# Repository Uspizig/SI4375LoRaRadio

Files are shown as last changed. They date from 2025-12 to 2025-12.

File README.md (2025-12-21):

# SensePuck_Radio: The Triple Tuner Platform for Meshtastic, LoRa, FM & AM

<p align="center"> 
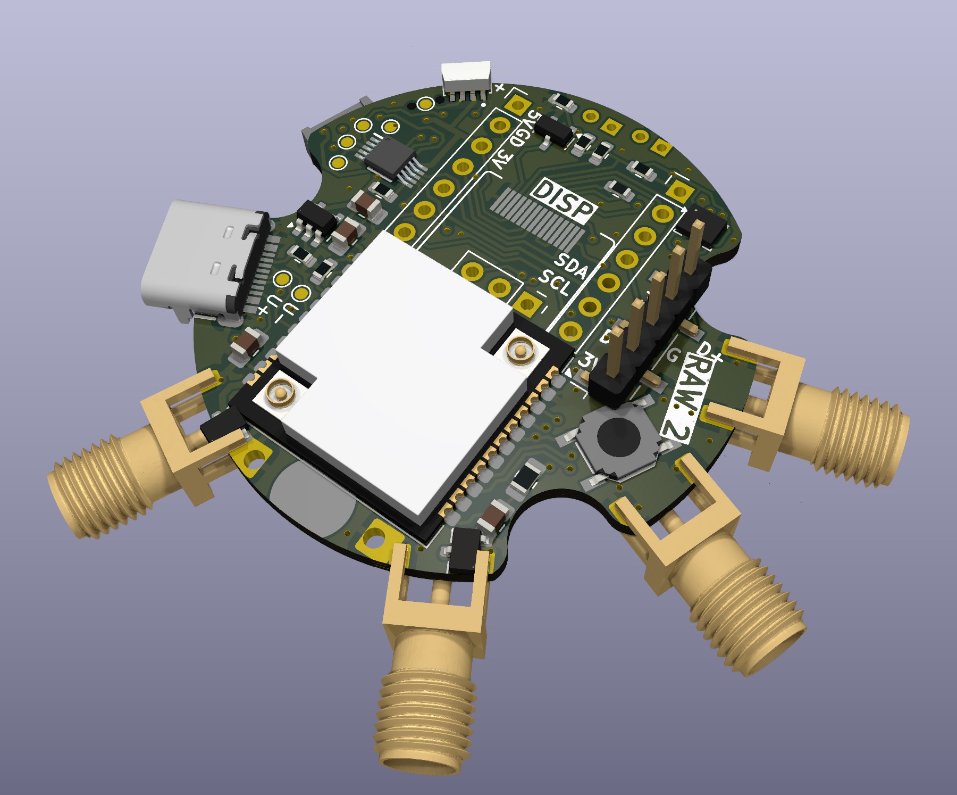
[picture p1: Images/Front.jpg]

</p>

<p align="center"> 
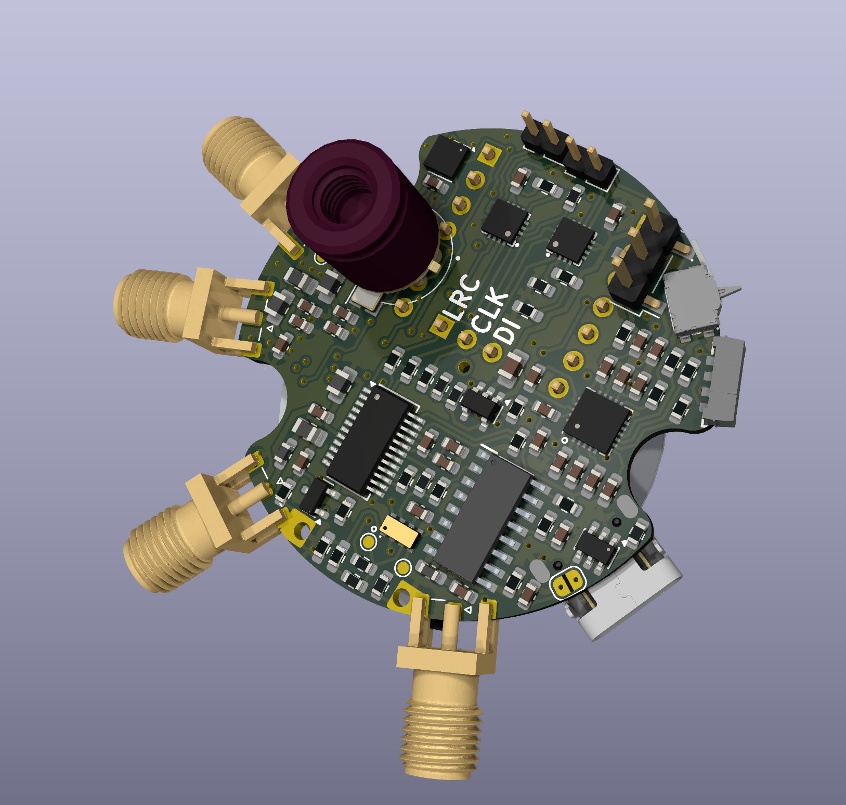
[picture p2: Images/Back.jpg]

</p>

 <p align="center"> 
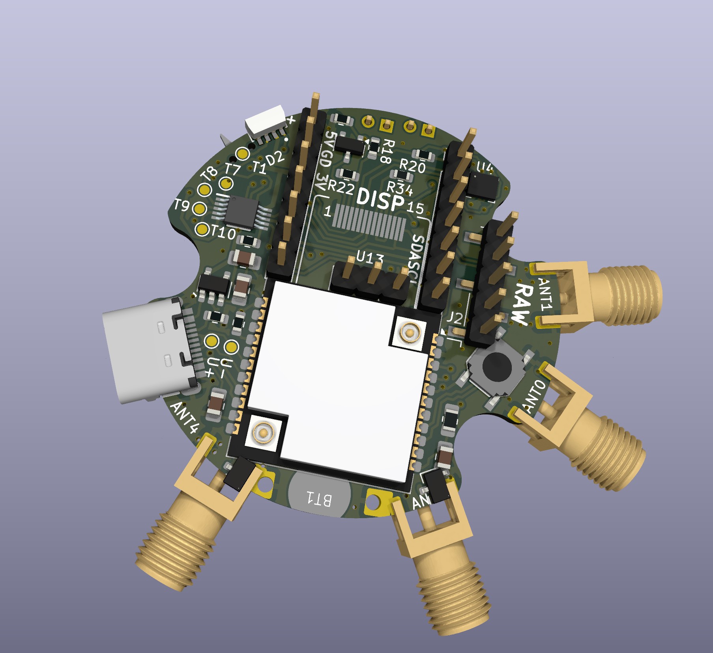
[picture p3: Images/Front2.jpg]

</p>

## Features:

1. **2xAudioAmplifier MAX98357**: Listen to your favourite Tunes with an Audio Amplifier

2. **SI4735 with Digital and Analog Audio**: Listen to AM/FM Radio

3. **SI4732 with Analog Audio**: Listen to AM/FM Radio

4.  **Heltec Lora HT-CT62 **: For Recieving and Transmitting LoRa, Meshtastic, TheThingsNetwork, Meshcore or decode your Bresser Weather Station

5.  SI5351 VCO Generator, 3 RF Outputs: 2.5 kHz to 160MHz 

6. **I2C Connector for Sensor**: Connect your favourite I2C Sensor board with the embedded 2.54mm connector

7. **Wireless Control**: Untehther your development process with the wireless capabilities. With WiFi and BLE, this tool allows remote control and data logging. Users can adjust settings and monitor data from a distance, offering a more flexible development experience.

8. **USB-C Connector**: for Debuggung and Power Supply

9. **LSM6 Gyro+ACC**: Check Movements, Steps Pedometer

10. TC4057 Battery Charger (Optional)

11. VEML 7700 Light Sensor (Optional)

12. GPS Sensor (Optional)

13. MLX90640/MLX90614 Thermal Sensor (Optional)

14. **Open Source & Programmable**: As an open-source device, the Device offers unmatched versatility. It is fully programmable, allowing you to tailor its functionality to your specific applications. This customization extends to software and hardware, opening up endless possibilities for creative and efficient project development.

15. **Compact Design**: Designed for convenience, the LoRaCam Board compact and sleek form factor allows for seamless integration into existing setups. Its compatibility with USB PD power sources and inline integration capability minimizes the need for additional equipment or extensive redesign, making it a versatile and user-friendly addition to any development environment.

16. **Display+Touchscreeen**: Monitor live the current status on an 1.8" or 1.28" LCD Touch Display

17. **RTC**: RealTimeClock RV3032 Temp Compensated for RealTime Clock

18. Extension Modules - Compatible to Seeed Sensors and Displays
<p align="center"> 
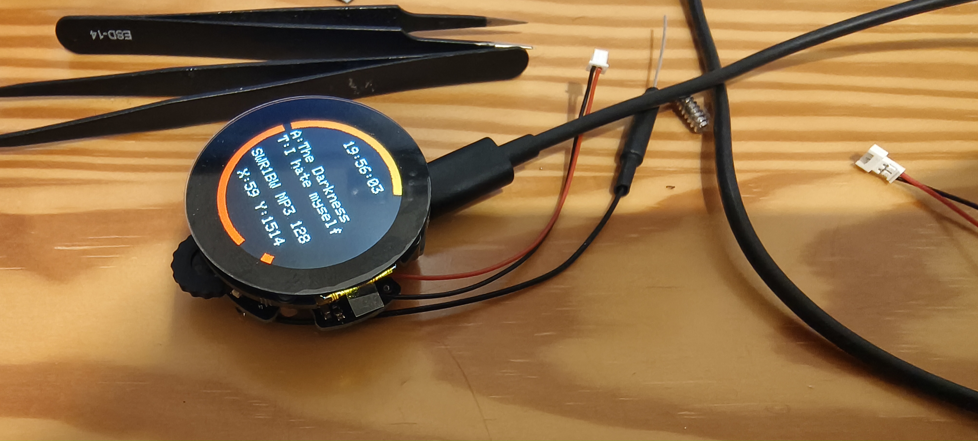
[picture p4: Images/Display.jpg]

</p>

19. **RGB LED**: Status LED WS2812-4020

20.  BME680: Measure Temperature, Humidity, Air Pressure, TVOC, eCO² (might update to BME688 or BME690 soon)
    
## Specifications

<p align="center"> 
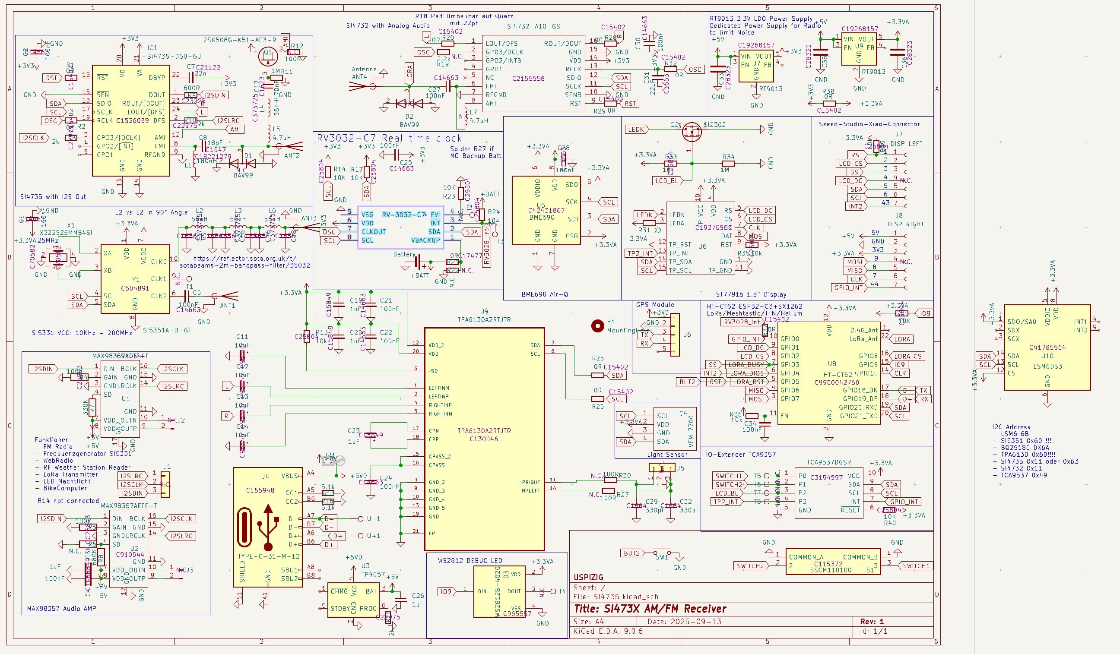
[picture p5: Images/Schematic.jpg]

</p>

<p align="center"> 
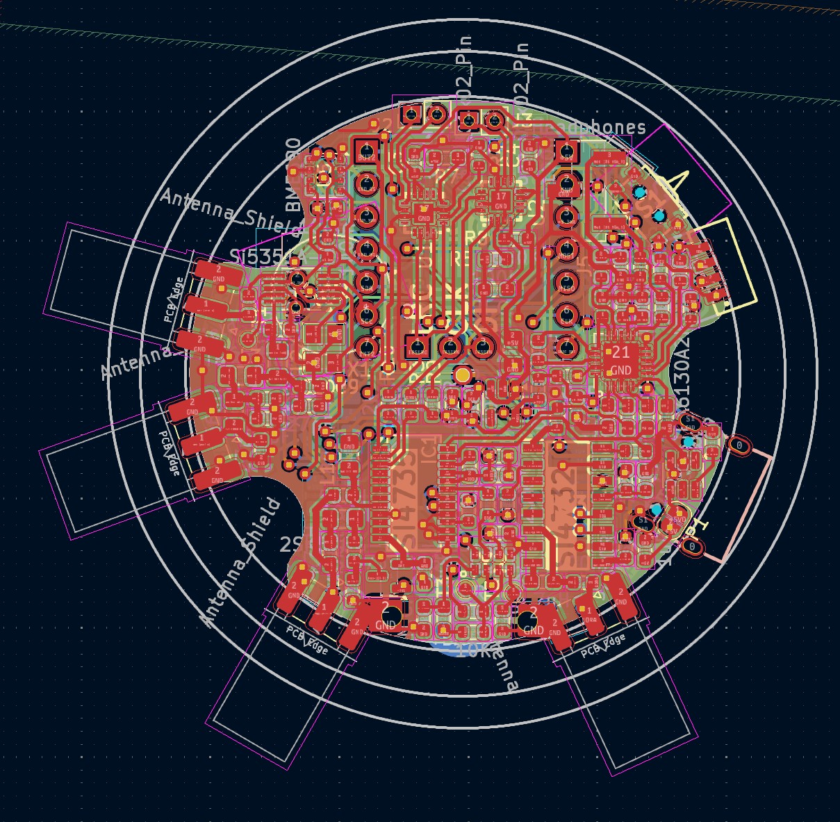
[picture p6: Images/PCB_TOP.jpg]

</p>

<p align="center"> 
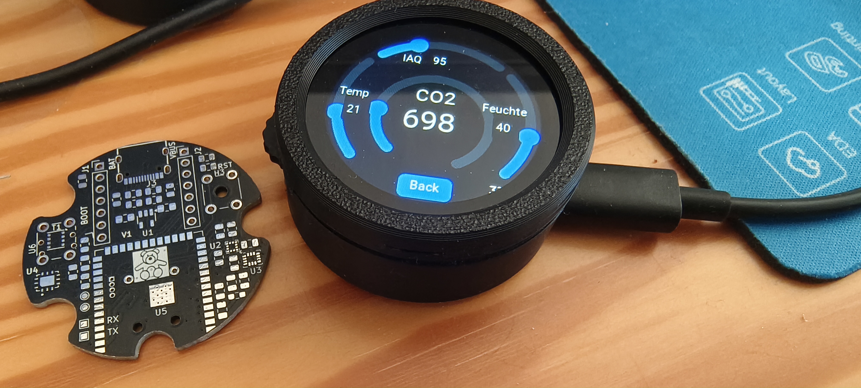
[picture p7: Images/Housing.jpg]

</p>

<p align="center"> 
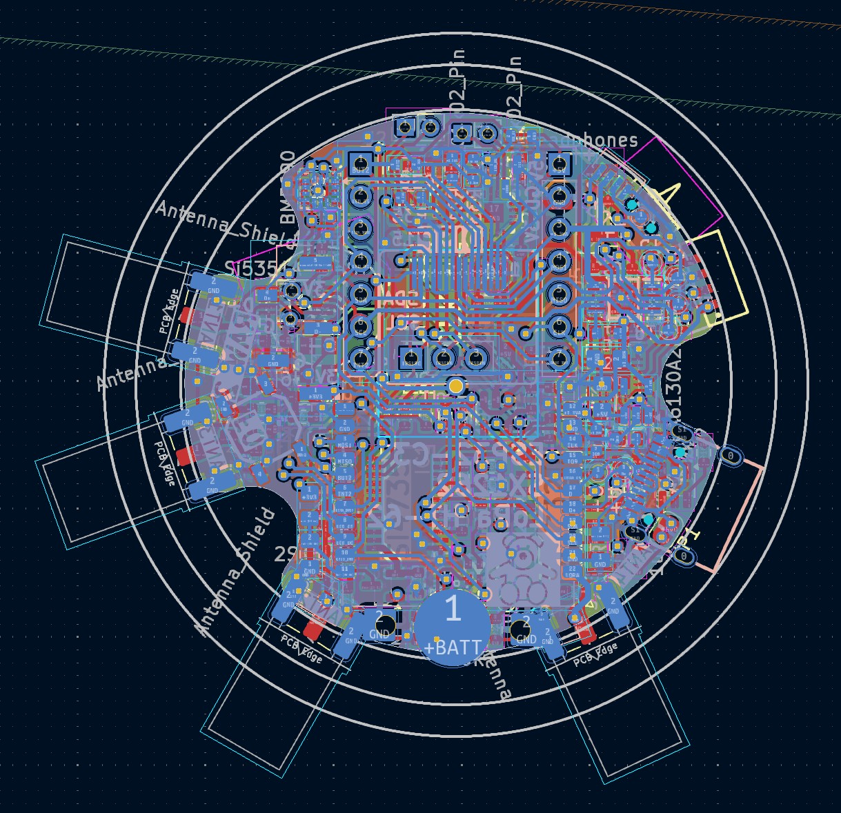
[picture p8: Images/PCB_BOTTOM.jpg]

</p>

Needed Libaries:

https://github.com/schreibfaul1/ESP32-audioI2S
https://github.com/pololu/lis3mdl-arduino
https://github.com/pololu/lsm6-arduino
https://github.com/Seeed-Projects/SeeedStudio_TFT_eSPI
https://github.com/Seeed-Projects/SeeedStudio_lvgl
https://github.com/Seeed-Studio/Seeed_Arduino_RoundDisplay

### Key Features:

### Future Developments:

AI Detection of objects, radio Signal and determine if the device shall sent the data via LoRa 

## Testing for Performance

At the heart of SensePuck's design is a commitment to reliability and performance. To ensure that SensePuck stands up to real-world demands, we subjected it to testing under use conditions.

## License

MIT License

Copyright (c) 2025 blue2monster

Permission is hereby granted, free of charge, to any person obtaining a copy
of this software and associated documentation files (the "Software"), to deal
in the Software without restriction, including without limitation the rights
to use, copy, modify, merge, publish, distribute, sublicense, and/or sell
copies of the Software, and to permit persons to whom the Software is
furnished to do so, subject to the following conditions:

The above copyright notice and this permission notice shall be included in all
copies or substantial portions of the Software.

THE SOFTWARE IS PROVIDED "AS IS", WITHOUT WARRANTY OF ANY KIND, EXPRESS OR
IMPLIED, INCLUDING BUT NOT LIMITED TO THE WARRANTIES OF MERCHANTABILITY,
FITNESS FOR A PARTICULAR PURPOSE AND NONINFRINGEMENT. IN NO EVENT SHALL THE
AUTHORS OR COPYRIGHT HOLDERS BE LIABLE FOR ANY CLAIM, DAMAGES OR OTHER
LIABILITY, WHETHER IN AN ACTION OF CONTRACT, TORT OR OTHERWISE, ARISING FROM,
OUT OF OR IN CONNECTION WITH THE SOFTWARE OR THE USE OR OTHER DEALINGS IN THE
SOFTWARE.

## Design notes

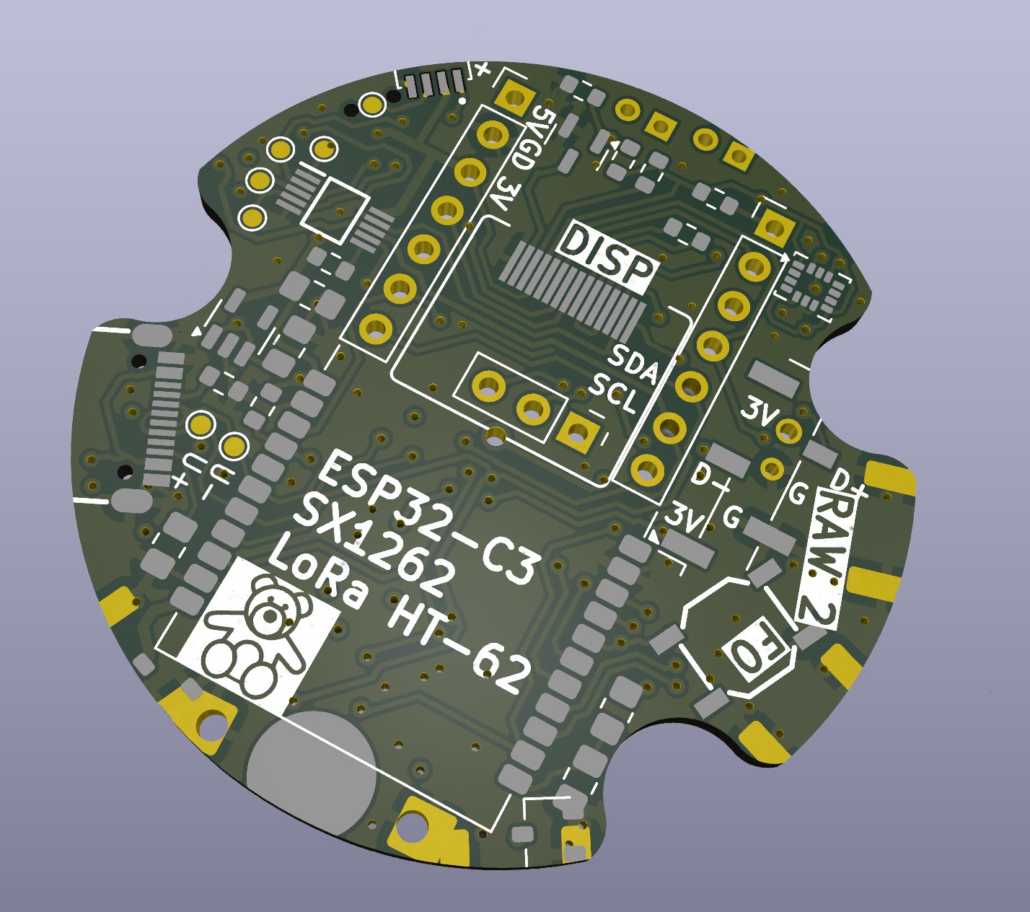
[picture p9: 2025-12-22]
Images/FrontRAW.jpg

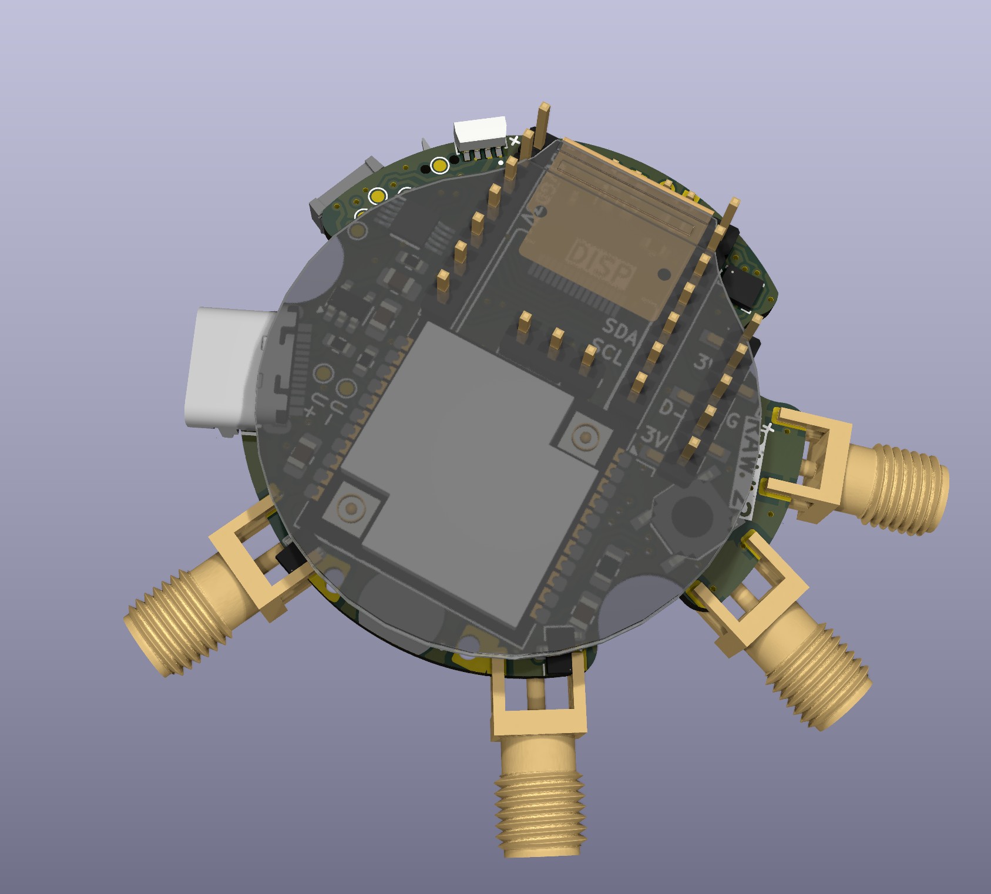
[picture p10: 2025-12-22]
Images/Front_Display.jpg

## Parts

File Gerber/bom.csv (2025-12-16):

Designator | Footprint | Quantity | Value | LCSC Part #
ANT0, ANT1, ANT5 | SMA_Samtec_SMA-J-P-H-ST-EM1_EdgeMount | 3 | Antenna_Shield
ANT4 | SMA_Samtec_SMA-J-P-H-ST-EM1_EdgeMount | 1 | Antenna
BT1 | MYOUNG MY-927-01 | 1 | Battery
C10, C11, C8, C9 | 0603 | 4 | 10uF
C14, C15, C16, C20 | 0603 | 4 | 1uF
C17, C18, C19, C21, C22, C23, C24, C27, C33, C37, C44, C49 | 0603 | 12 | 100nF
C28, C29, C30 | 0805 | 3 | 1uF
C32 | 0603 | 1 | 22n
C34, C39 | 0603 | 2 | 270p
C36 | 0603 | 1 | 18pF
C38, C40, C41, C43, C46, C47 | 0603 | 6 | 27pF
C42 | 0603 | 1 | 22pF
C45 | 0805 | 1 | 100nF
C48 | 0603 | 1 | 470nF
D2 | LED_WS2812B-4020 | 1 | WS2812B-4020
D6, D7 | SOT-23W | 2 | BAV99
IC1 | SOIC127P600X175-16N | 1 | SI4732-A10-GS
IC2 | SOP50P490X110-10N | 1 | TCA9537DGSR
J1 | PinHeader_1x03_P2.54mm_Vertical | 1 | Conn_01x03
J2 | PinHeader_1x05_P2.54mm_Vertical_SMD_Pin1Right | 1 | Conn_01x05
J3 | PinHeader_1x03_P2.54mm_Vertical_SMD_Pin1Left | 1 | Headphones
J5 | PinHeader_1x07_P2.54mm_Vertical | 1 | DISP LEFT
J6 | PinHeader_1x07_P2.54mm_Vertical | 1 | DISP RIGHT
J7, J9 | PinHeader_1x02_P2.00mm_Vertical | 2 | Conn_01x02_Pin
J8 | USB-C_SMD-TYPE-C-31-M-12 | 1 | TYPE-C-31-M-12
L1, L2, L3, L6 | 0805 | 4 | 56nH
L4 | 0805 | 1 | 180nH
L5 | 0805 | 1 | 4.7uH
L7 | 0603 | 1 | 4.7uH
Q2 | SOT-23 | 1 | 2N7002
Q3 | SOT-23 | 1 | 2SK508G-K51-AE3-R
R1, R18, R20, R34, R47, R52 | 0603 | 6 | 10k
R10, R11, R48 | 0603 | 3 | 100R
R12, R13, R24, R25 | 0603 | 4 | 10K | C17414
R14 | 0603 | 1 | N.C.
R15 | 0603 | 1 | 0R | C17414
R16, R7 | 0603 | 2 | 100K
R17 | 0603 | 1 | 680K
R19, R50 | 0603 | 2 | 1M
R2, R23, R26, R28, R39, R45, R53, R8, R9 | 0603 | 9 | 0R
R21 | 0603 | 1 | 330K
R22 | 0603 | 1 | 22
R27 | 0603 | 1 | N.C. | C17414
R38, R40, R41 | 0603 | 3 | 2k
R42 | 0603 | 1 | 600R
R44 | 0805 | 1 | 10k
R46 | 0805 | 1 | 0R
R49 | 0603 | 1 | 5.1k
R51 | 0805 | 1 | 5.1k
S1 | SSCM110100 | 1 | SSCM110100
SW1 | SW-SMD_4P-CORR-L5.2-W5.2-P3.70-LS6.4 | 1 | SW_Push
T1, T10, T11, T5, T6, T7, T8, T9 | TestPoint_Pad_D1.0mm | 8 | TestPoint
U+1 | TestPoint_Pad_D1.0mm | 1 | U+
U-1 | TestPoint_Pad_D1.0mm | 1 | U-
U1 | Heltec_HT-CT62 | 1 | HT-CT62
U11, U6 | SOT-23-5 | 2 | RT9013
U13 | GC9A01_Touch_IPS_display_reversed_16pin | 1 | ~
U2 | Bosch_LGA-8_3x3mm_P0.8mm_ClockwisePinNumbering | 1 | BME690
U4 | LGA-14_3x2.5mm_P0.5mm_LayoutBorder3x4y | 1 | LSM6DS3
U5 | QFN-20-1EP_4x4mm_P0.5mm_EP2.7x2.7mm | 1 | TPA6130A2RTJTR | TPA6130A2RTJTR
U7, U8 | TQFN-16_L3.0-W3.0-P0.50-BL-EP1.5 | 2 | MAX98357AETE+T
U9 | SSOP-24_3.9x8.7mm_P0.635mm | 1 | Si4735-D60-GU
X1 | Crystal_SMD_3225-4Pin_3.2x2.5mm | 1 | X322525MMB4SI
Y1 | MSOP-10_3x3mm_P0.5mm | 1 | Si5351A-B-GT
Y2 | RV3032C7 | 1 | RV-3032-C7

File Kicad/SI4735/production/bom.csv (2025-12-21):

Designator | Footprint | Quantity | Value | LCSC Part #
ANT1, ANT2, ANT3 | SMA_Samtec_SMA-J-P-H-ST-EM1_EdgeMount | 3 | Antenna_Shield
ANT4 | SMA_Samtec_SMA-J-P-H-ST-EM1_EdgeMount | 1 | Antenna
BT1 | MYOUNG MY-927-01 | 1 | Battery
C1, C2, C22, C23, C25, C26, C27, C28, C31, C4, C6 | 0603 | 11 | 100nF
C10, C20, C21, C24, C3 | 0603 | 5 | 1uF
C11, C16, C17, C19, C5, C9 | 0603 | 6 | 27pF
C12, C13, C14, C15 | 0603 | 4 | 10uF
C18 | 0603 | 1 | 470nF
C30, C33 | 0603 | 2 | 330pF
C32 | 0603 | 1 | 22pF
C34, C36, C37 | 0805 | 3 | 1uF
C35 | 0805 | 1 | 100nF
C7 | 0603 | 1 | 22n
C8 | 0603 | 1 | 18pF
D1, D2 | SOT-23W | 2 | BAV99
D3 | LED_WS2812B-4020 | 1 | WS2812B-4020
IC1 | SOIC127P600X175-16N | 1 | SI4732-A10-GS
IC2 | VEML7700 | 1 | VEML7700
IC3 | SOP50P490X110-10N | 1 | TCA9537DGSR
IC4 | MLX90640ESFBAB000SP | 1 | MLX90640ESF-BAB-000-SP
J1 | PinHeader_1x03_P2.54mm_Vertical | 1 | Conn_01x03
J2, J3 | PinHeader_1x02_P2.00mm_Vertical | 2 | Conn_01x02_Pin
J4 | USB-C_SMD-TYPE-C-31-M-12 | 1 | TYPE-C-31-M-12
J5 | PinHeader_1x03_P2.54mm_Vertical_SMD_Pin1Left | 1 | Headphones
J6 | PinHeader_1x05_P2.54mm_Vertical_SMD_Pin1Right | 1 | Conn_01x05
J7 | PinHeader_1x07_P2.54mm_Vertical | 1 | DISP LEFT
J8 | PinHeader_1x07_P2.54mm_Vertical | 1 | DISP RIGHT
JP1 | SolderJumper-2_P1.3mm_Open_RoundedPad1.0x1.5mm | 1 | Jumper_2_Small_Open
L1 | 0805 | 1 | 180nH
L2, L3, L4, L6 | 0805 | 4 | 56nH
L5, L7 | 0603 | 2 | 4.7uH
Q1 | SOT-23 | 1 | 2SK508G-K51-AE3-R
Q2 | SOT-23 | 1 | SI2302
R1, R18, R19, R2, R24, R25, R28, R29, R31, R36, R37 | 0603 | 11 | 0R
R10, R3, R41 | 0603 | 3 | 2k
R11, R33 | 0603 | 2 | 1M
R12, R26, R27 | 0603 | 3 | 100R
R13, R32, R34, R38, R39, R40 | 0603 | 6 | 10k
R14, R17, R22, R23 | 0603 | 4 | 10K | C17414
R15 | 0603 | 1 | 5.1k
R16 | 0805 | 1 | 5.1k
R20 | 0603 | 1 | 0R | C17477
R21 | 0603 | 1 | N.C. | C17414
R30 | 0603 | 1 | 22
R35 | 0805 | 1 | 10k
R4, R5 | 0603 | 2 | 100K
R6 | 0603 | 1 | N.C.
R7 | 0603 | 1 | 330K
R8 | 0603 | 1 | 680K
R9 | 0603 | 1 | 600R
S1 | SSCM110100 | 1 | SSCM110100
SW1 | SW-SMD_4P-CORR-L5.2-W5.2-P3.70-LS6.4 | 1 | SW_Push
T1, T2, T3, T4, T5, T6, T7, T8 | TestPoint_Pad_D1.0mm | 8 | TestPoint
U+1 | TestPoint_Pad_D1.0mm | 1 | U+
U-1 | TestPoint_Pad_D1.0mm | 1 | U-
U1 | SSOP-24_3.9x8.7mm_P0.635mm | 1 | Si4735-D60-GU
U10 | LGA-14_3x2.5mm_P0.5mm_LayoutBorder3x4y | 1 | LSM6DS3
U12 | TSOT-23-6 | 1 | TP4057
U2, U3 | TQFN-16_L3.0-W3.0-P0.50-BL-EP1.5 | 2 | MAX98357AETE+T
U4 | QFN-20-1EP_4x4mm_P0.5mm_EP2.7x2.7mm | 1 | TPA6130A2RTJTR | TPA6130A2RTJTR
U5 | Bosch_LGA-8_3x3mm_P0.8mm_ClockwisePinNumbering | 1 | BME690
U6 | GC9A01_Touch_IPS_display_reversed_16pin | 1 | ~
U7, U9 | SOT-23-5 | 2 | RT9013
U8 | Heltec_HT-CT62 | 1 | HT-CT62
X1 | Crystal_SMD_3225-4Pin_3.2x2.5mm | 1 | X322525MMB4SI
Y1 | MSOP-10_3x3mm_P0.5mm | 1 | Si5351A-B-GT
Y2 | RV3032C7 | 1 | RV-3032-C7

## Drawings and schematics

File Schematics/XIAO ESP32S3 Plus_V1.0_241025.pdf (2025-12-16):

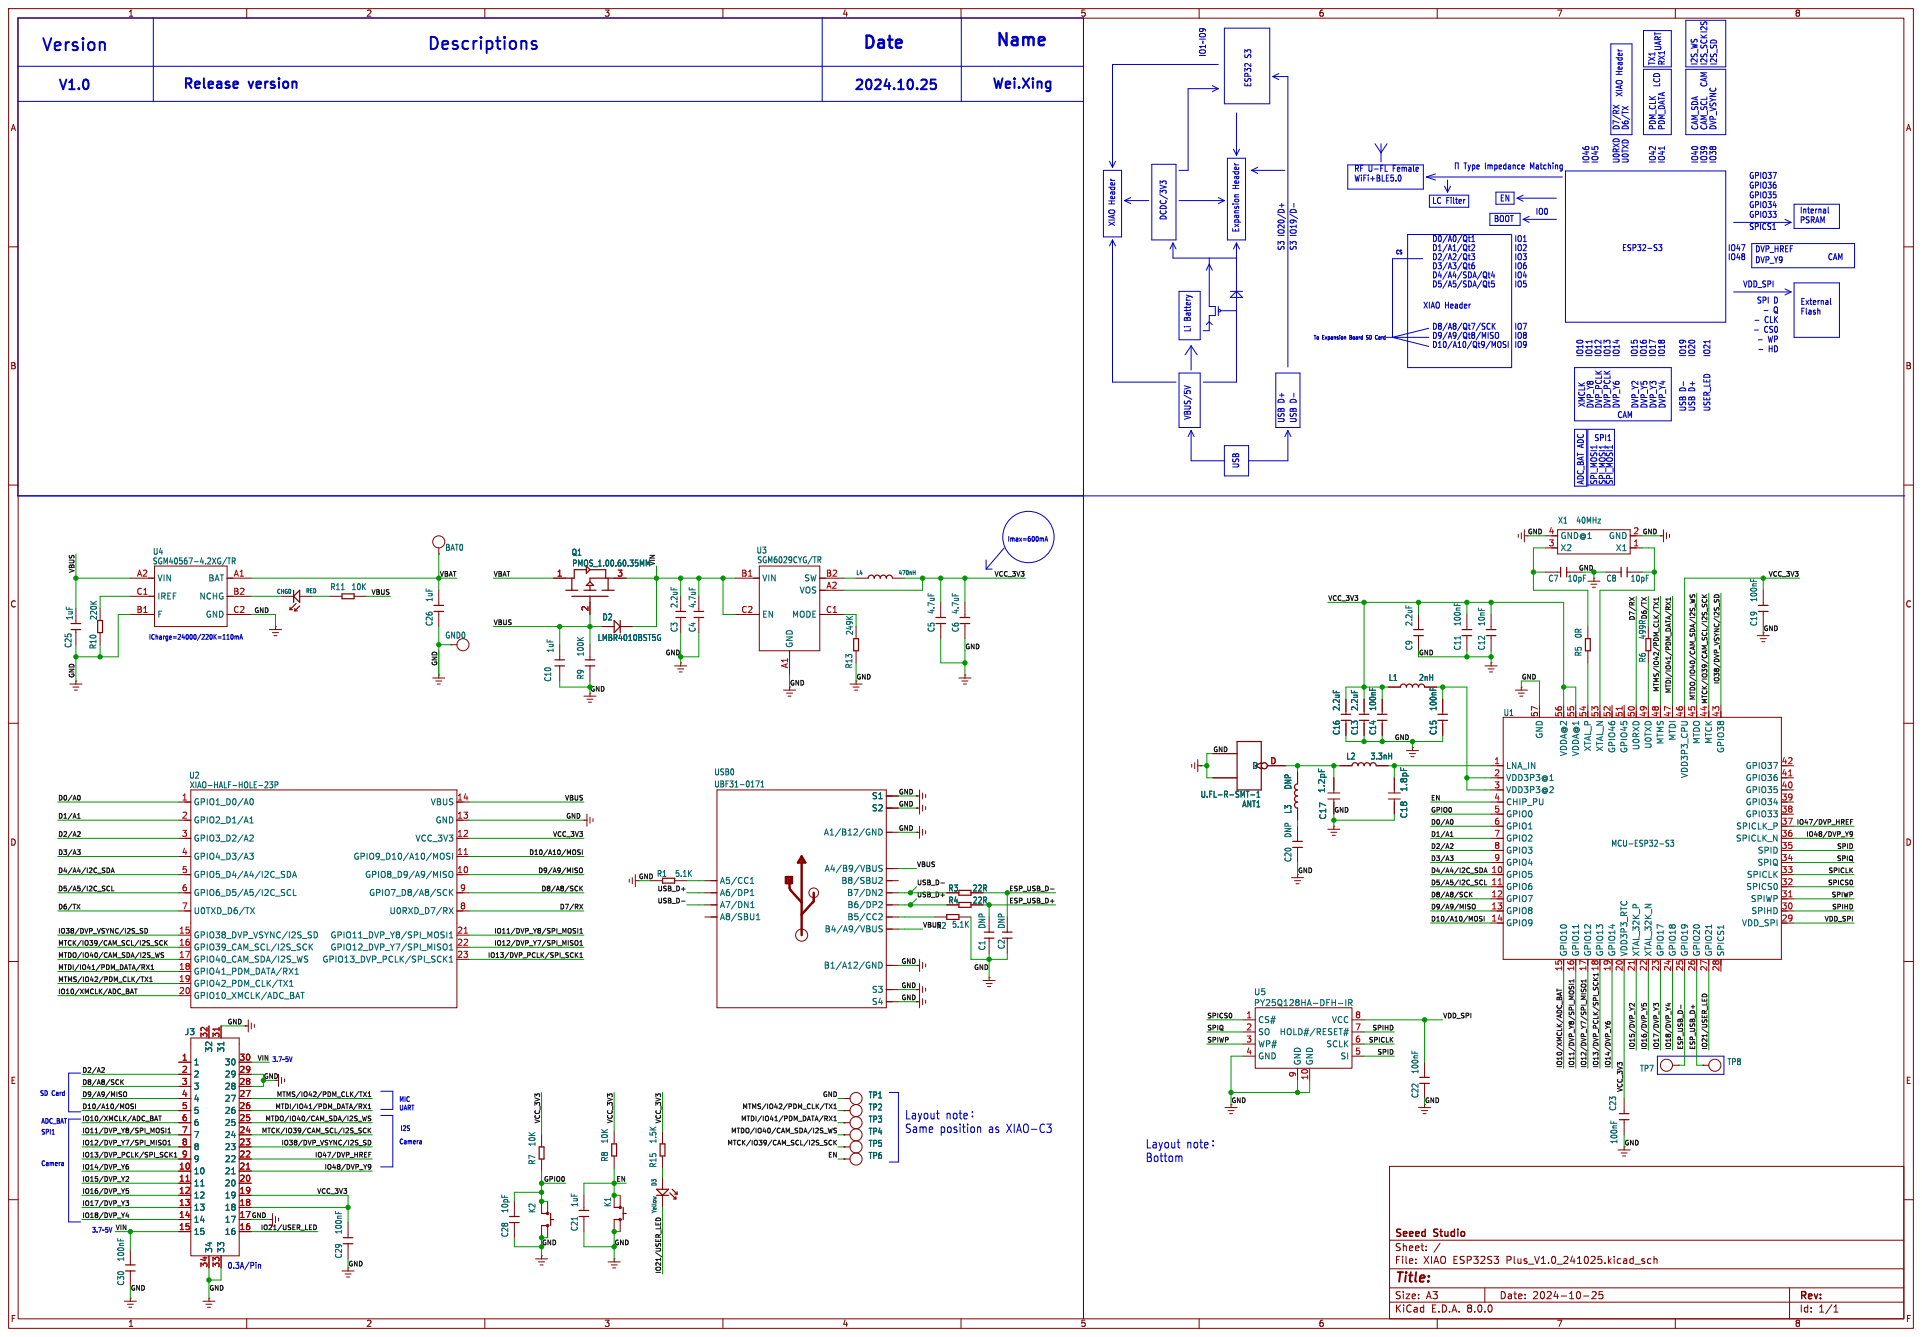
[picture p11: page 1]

IO9 RF U-FL Female WiFi+BLE5.0

þÿ Type Impedance Matching EN

D10/A10/MOSI VCC_3V3 D9/A9/MISO GND MTDI/IO41/PDM_DATA/RX1

IO38/DVP_VSYNC/I2S_SD MTDO/IO40/CAM_SDA/I2S_WS MTCK/IO39/CAM_SCL/I2S_SCK D6/TX MTMS/IO42/PDM_CLK/TX1

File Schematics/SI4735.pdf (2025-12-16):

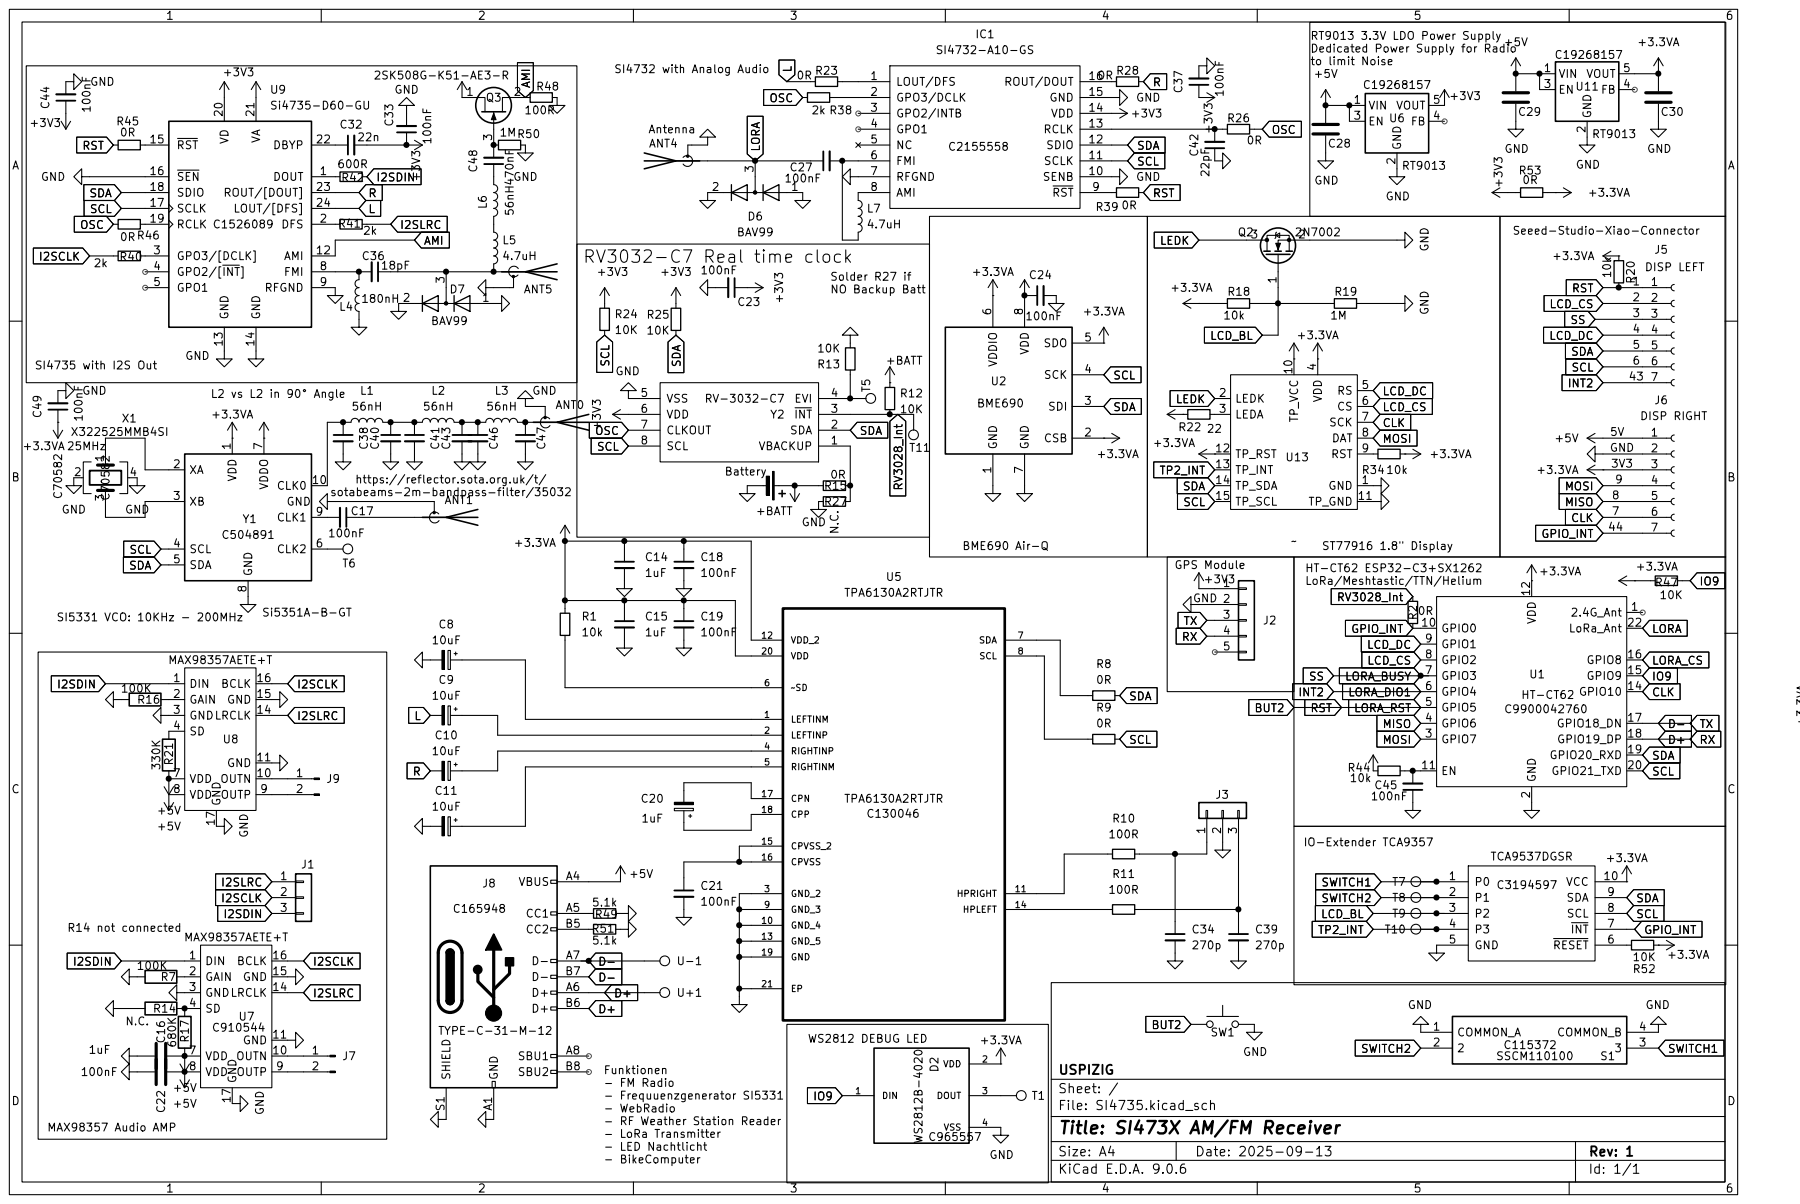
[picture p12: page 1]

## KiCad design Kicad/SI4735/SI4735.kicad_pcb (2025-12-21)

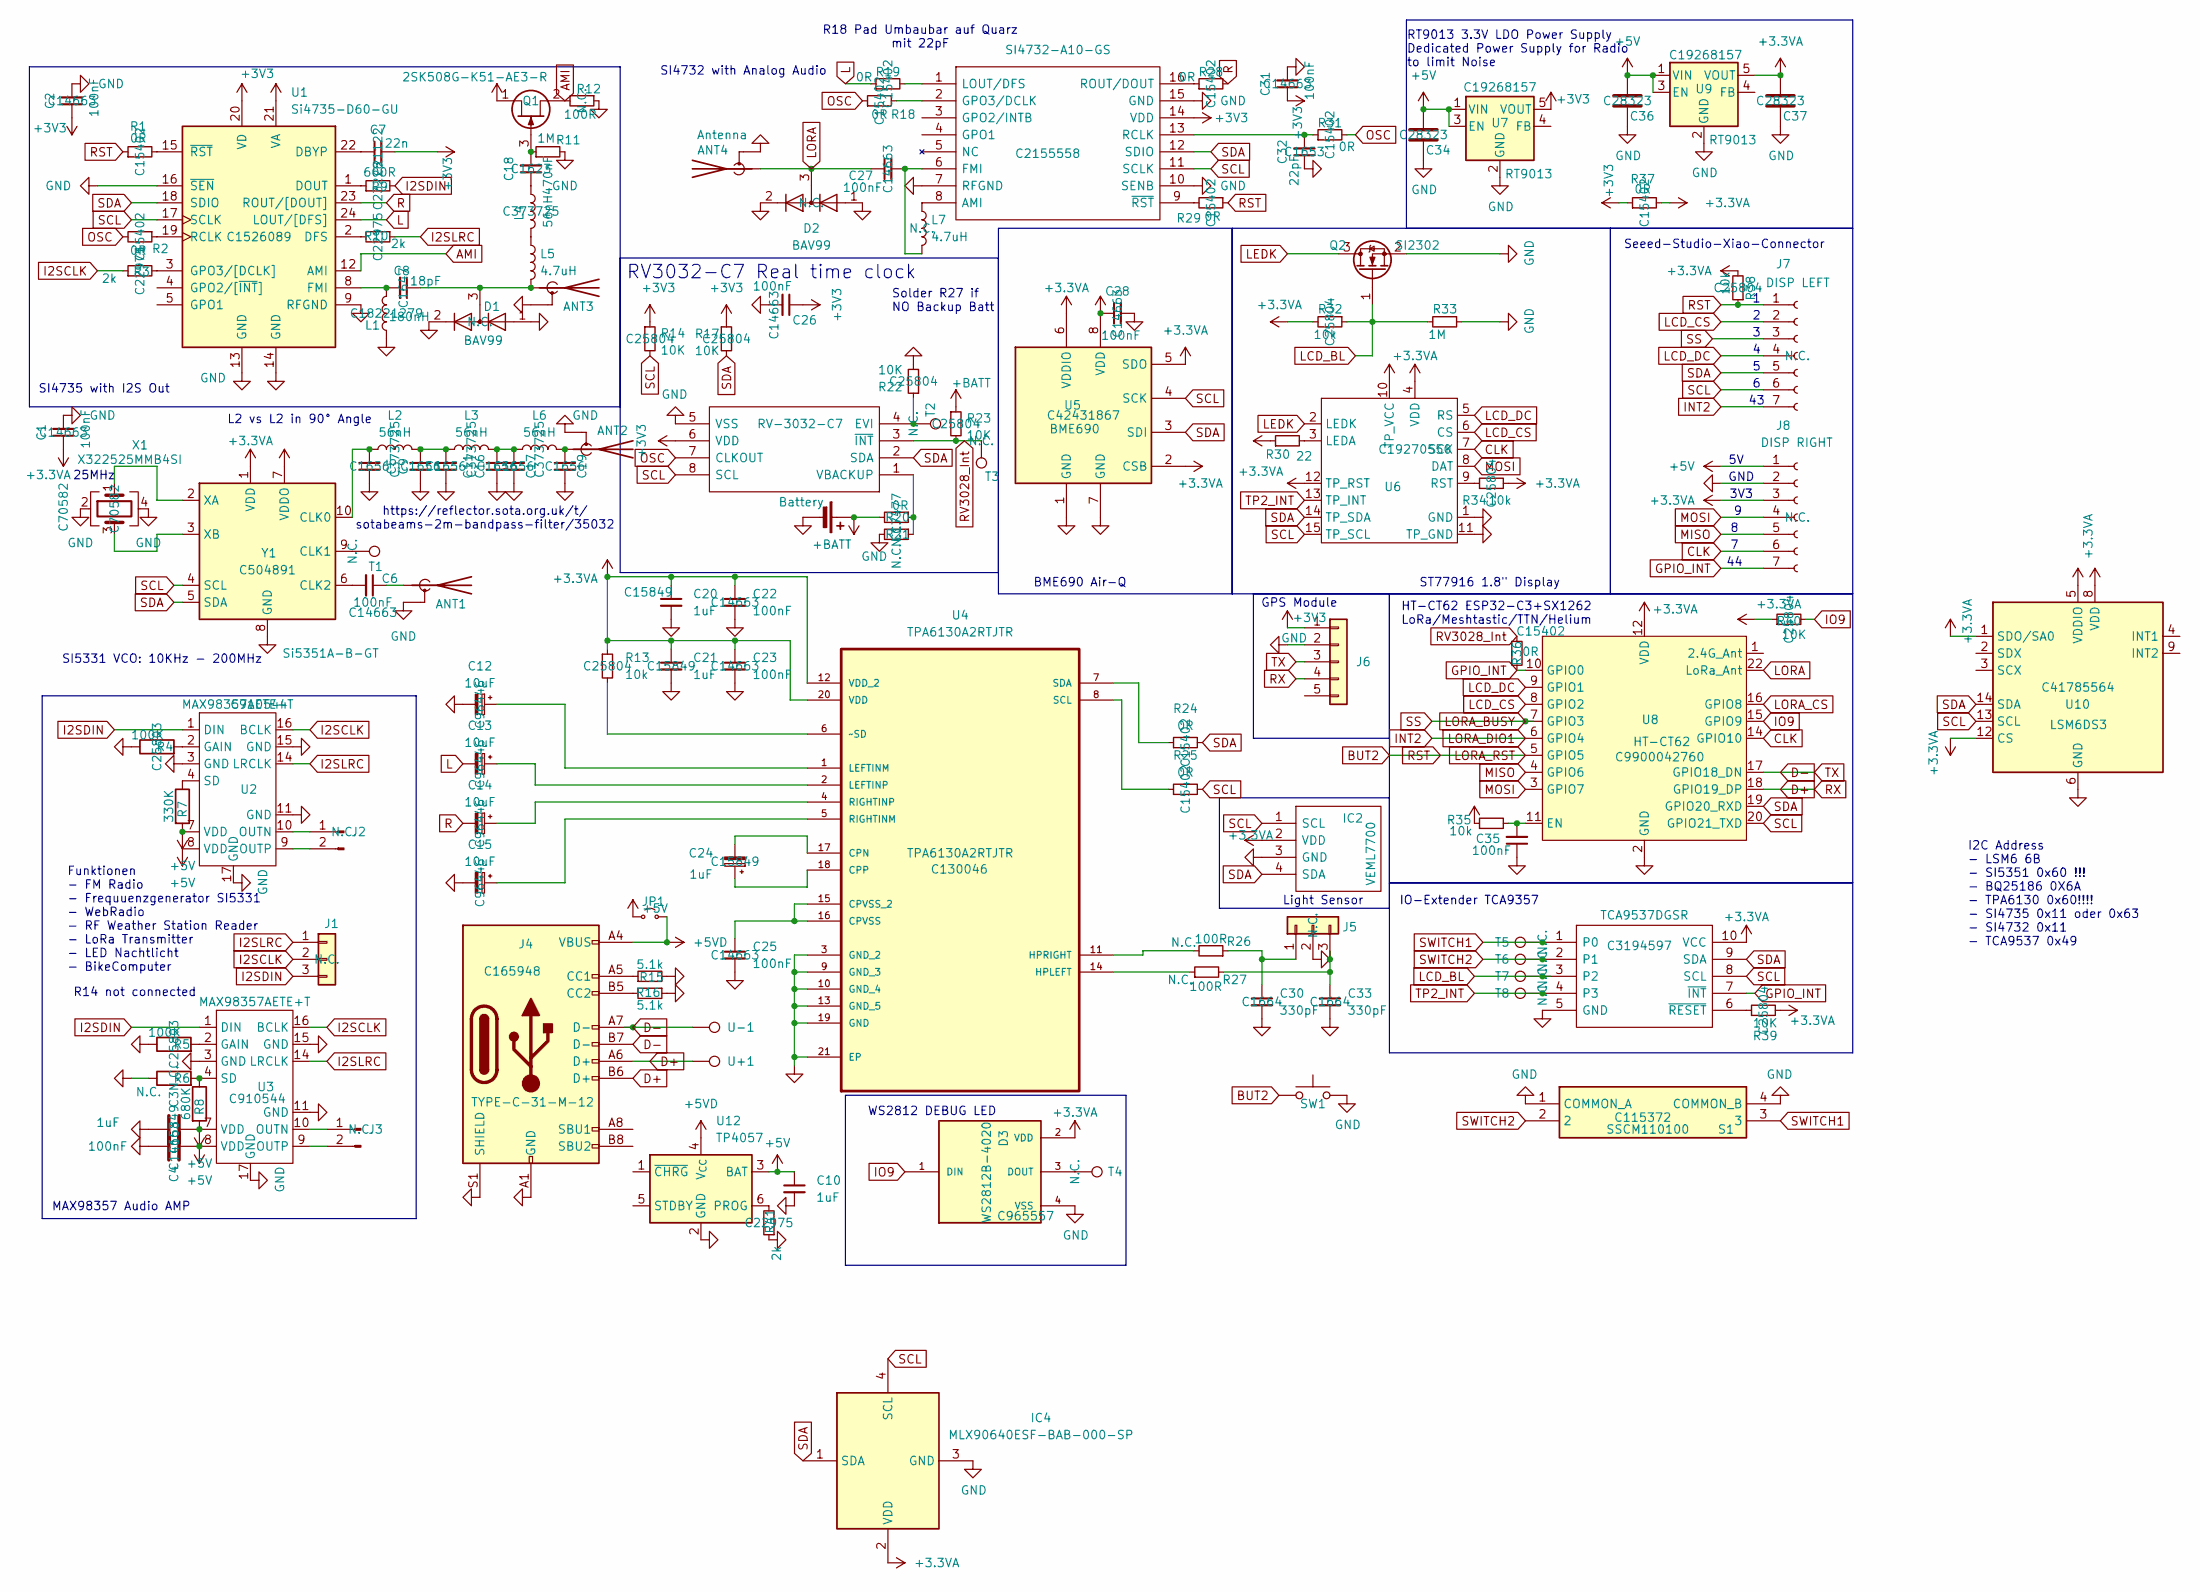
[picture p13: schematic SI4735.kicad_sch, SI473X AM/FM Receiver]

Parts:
ANT1, ANT2, ANT3: Antenna_Shield; SMA_Samtec_SMA-J-P-H-ST-EM1_EdgeMount
ANT4: Antenna; SMA_Samtec_SMA-J-P-H-ST-EM1_EdgeMount
BT1: Battery; MYOUNG MY-927-01
C1, C2, C4, C6, C22, C23, C25, C26, C27, C28, C31: 100nF; C_0603_1608Metric; LCSC Part Name C14663
C3, C10, C20, C21, C24: 1uF; C_0603_1608Metric; LCSC Part Name C15849
C5, C9, C11, C16, C17, C19: 27pF; C_0603_1608Metric; LCSC Part Name C1656
C7: 22n; C_0603_1608Metric; LCSC Part Name C21122
C8: 18pF; C_0603_1608Metric; LCSC Part Name C1647
C12, C13, C14, C15: 10uF; C_0603_1608Metric_Pad1.08x0.95mm_HandSolder; LCSC Part Name C96446
C18: 470nF; C_0603_1608Metric; LCSC Part Name C1623
C30, C33: 330pF; C_0603_1608Metric; LCSC Part Name C1664
C32: 22pF; C_0603_1608Metric; LCSC Part Name C1653
C34, C36, C37: 1uF; C_0805_2012Metric_Pad1.18x1.45mm_HandSolder; LCSC Part Name C28323
C35: 100nF; C_0805_2012Metric_Pad1.18x1.45mm_HandSolder
D1, D2: BAV99; SOT-23W; LCSC Part Name N.C.
D3: WS2812B-4020; LED_WS2812B-4020; PARTREV V1.2; LCSC Part Name C965557
IC1: SI4732-A10-GS; SOIC127P600X175-16N; Mouser Part Number 634-SI4732-A10-GS
IC2: VEML7700; Mouser Part Number 78-VEML7700-TR
IC3: TCA9537DGSR; SOP50P490X110-10N; Mouser Part Number 595-TCA9537DGSR
IC4: MLX90640ESF-BAB-000-SP; MLX90640ESFBAB000SP; Mouser Part Number 482-MLX90640ESFBABSP
J1: Conn_01x03; PinHeader_1x03_P2.54mm_Vertical; LCSC Part Name N.C.
J2, J3: Conn_01x02_Pin; PinHeader_1x02_P2.00mm_Vertical; LCSC Part Name N.C.
J4: TYPE-C-31-M-12; USB-C_SMD-TYPE-C-31-M-12; LCSC Part Name C165948
J5: Headphones; PinHeader_1x03_P2.54mm_Vertical_SMD_Pin1Left; LCSC Part Name N.C.
J6: Conn_01x05; PinHeader_1x05_P2.54mm_Vertical_SMD_Pin1Right; LCSC Part Name N.C.
J7: DISP LEFT; PinHeader_1x07_P2.54mm_Vertical; LCSC Part Name N.C.
J8: DISP RIGHT; PinHeader_1x07_P2.54mm_Vertical; LCSC Part Name N.C.
JP1: Jumper_2_Small_Open; SolderJumper-2_P1.3mm_Open_RoundedPad1.0x1.5mm
L1: 180nH; L_0805_2012Metric_Pad1.15x1.40mm_HandSolder; LCSC Part Name C18221279
L2, L3, L4, L6: 56nH; L_0805_2012Metric_Pad1.15x1.40mm_HandSolder; LCSC Part Name C373725
L5: 4.7uH; L_0603_1608Metric_Pad1.05x0.95mm_HandSolder
L7: 4.7uH; L_0603_1608Metric_Pad1.05x0.95mm_HandSolder; LCSC Part Name N.C.
Q1: 2SK508G-K51-AE3-R; SOT-23
Q2: SI2302; SOT-23
R1, R2, R18, R19, R24, R25, R28, R29, R31, R36, R37: 0R; R_0603_1608Metric; LCSC Part Name C15402
R3, R10, R41: 2k; R_0603_1608Metric; LCSC Part Name C22975
R4, R5: 100K; R_0603_1608Metric; LCSC Part Name C25803
R6: N.C.; R_0603_1608Metric_Pad0.98x0.95mm_HandSolder; LCSC Part Name N.C.
R7: 330K; R_0603_1608Metric_Pad0.98x0.95mm_HandSolder
R8: 680K; R_0603_1608Metric_Pad0.98x0.95mm_HandSolder
R9: 600R; R_0603_1608Metric; LCSC Part Name C23228
R11, R33: 1M; R_0603_1608Metric
R12, R26, R27: 100R; R_0603_1608Metric; LCSC Part Name N.C.
R13, R32, R34, R38: 10k; R_0603_1608Metric; LCSC Part Name C25804
R14, R17, R22, R23: 10K; R_0603_1608Metric; LCSC C17414
R15: 5.1k; R_0603_1608Metric
R16: 5.1k; C_0805_2012Metric_Pad1.18x1.45mm_HandSolder
R20: 0R; R_0603_1608Metric_Pad0.98x0.95mm_HandSolder; LCSC C17477
R21: N.C.; R_0603_1608Metric_Pad0.98x0.95mm_HandSolder; LCSC C17414
R30: 22; R_0603_1608Metric
R35: 10k; R_0805_2012Metric_Pad1.20x1.40mm_HandSolder
R39, R40: 10K; R_0603_1608Metric; LCSC Part Name C25804
S1: SSCM110100; Mouser Part Number 688-SSCM110100
SW1: SW_Push; SW-SMD_4P-CORR-L5.2-W5.2-P3.70-LS6.4
T1, T2, T3, T4, T5, T6, T7, T8: TestPoint; TestPoint_Pad_D1.0mm; LCSC Part Name N.C.
U1: Si4735-D60-GU; SSOP-24_3.9x8.7mm_P0.635mm; LCSC Part Name C1526089
U2, U3: MAX98357AETE+T; TQFN-16_L3.0-W3.0-P0.50-BL-EP1.5; LCSC Part Name C910544
U4: TPA6130A2RTJTR; QFN-20-1EP_4x4mm_P0.5mm_EP2.7x2.7mm; MPN TPA6130A2RTJTR; LCSC Part Name C130046
U5: BME690; Bosch_LGA-8_3x3mm_P0.8mm_ClockwisePinNumbering; LCSC Part Name C42431867
U6: GC9A01_Touch_IPS_display_reversed_16pin; LCSC Part Name C19270550
U7, U9: RT9013; SOT-23-5; LCSC Part Name C19268157
U8: HT-CT62; Heltec_HT-CT62; LCSC Part Name C9900042760
U10: LSM6DS3; LGA-14_3x2.5mm_P0.5mm_LayoutBorder3x4y; LCSC Part Name C41785564
U12: TP4057; TSOT-23-6; LCSC Part Name C12044
U+1: U+; TestPoint_Pad_D1.0mm; LCSC Part Name N.C.
U-1: U-; TestPoint_Pad_D1.0mm; LCSC Part Name N.C.
X1: X322525MMB4SI; Crystal_SMD_3225-4Pin_3.2x2.5mm; LCSC Part Name C70582
Y1: Si5351A-B-GT; MSOP-10_3x3mm_P0.5mm; LCSC Part Name C504891
Y2: RV-3032-C7; RV3032C7; Mouser Part Number 428-203853-MG01

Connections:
+3.3VA: C1.1, C20.1, C21.1, C22.1, C23.1, C28.1, C37.2, D3.2 (VDD), IC2.2 (VDD), IC3.10 (VCC), IC4.2 (VDD), J8.3, R13.1, R30.1, R32.2, R34.2, R37.2, R38.2, R39.2, R40.1, U4.12 (VDD_2), U4.20 (VDD), U5.2 (CSB), U5.5 (SDO), U5.6 (VDDIO), U5.8 (VDD), U6.4 (VDD), U6.10 (TP_VCC), U6.12 (TP_RST), U8.12 (VDD), U9.5 (VOUT), U10.1 (SDO/SA0), U10.5 (VDDIO), U10.8 (VDD), U10.12 (CS), Y1.1 (VDD), Y1.7 (VDDO)
+3V3: C2.1, C7.2, C26.1, C31.1, IC1.14 (VDD), J6.1, Q1.1 (D), R14.1, R17.1, R35.1, R37.1, U1.20 (VD), U1.21 (VA), U7.5 (VOUT), Y2.6 (VDD)
+5V: C3.1, C4.1, C10.1, C34.2, C36.2, J8.1, JP1.2 (B), R7.2, R8.2, U2.7 (VDD), U2.8 (VDD), U3.7 (VDD), U3.8 (VDD), U7.1 (VIN), U7.3 (EN), U9.1 (VIN), U9.3 (EN), U12.3 (BAT)
+5VD: J4.A4 (VBUS), J4.A9 (VBUS), J4.B4 (VBUS), J4.B9 (VBUS), JP1.1 (A), U12.4 (V_{CC})
+BATT: BT1.1 (+), R20.2, R23.1
AMI: Q1.2 (S), R12.2, U1.12 (AMI)
BUT2: J7.1, R1.1, R29.1, R38.1, SW1.1, U8.5 (GPIO5)
CLK: J8.6, U6.7 (SCK), U8.14 (GPIO10)
D+: J4.A6 (D+), J4.B6 (D+), J6.4, U8.18 (GPIO19_DP), U+1.1
D-: J4.A7 (D-), J4.B7 (D-), J6.3, U8.17 (GPIO18_DN), U-1.1
GND: ANT1.2 (Shield), ANT2.2 (Shield), ANT3.2 (Shield), ANT4.2 (Shield), BT1.2 (-), C1.2, C2.2, C3.2, C4.2, C5.2, C9.2, C10.2, C11.2, C12.2, C15.2, C16.2, C17.2, C19.2, C20.2, C21.2, C22.2, C23.2, C25.2, C26.2, C28.2, C30.2, C31.2, C32.1, C33.2, C34.1, C35.1, C36.1, C37.1, D1.1 (K), D1.2 (A), D2.1 (K), D2.2 (A), D3.4 (VSS), IC1.7 (RFGND), IC1.10 (SENB), IC1.15 (GND), IC2.3 (GND), IC3.5 (GND), IC4.3 (GND), J4.A1 (GND), J4.A12 (GND), J4.B1 (GND), J4.B12 (GND), J4.S1 (SHIELD), J5.2, J6.2, J8.2, L1.1, Q2.2 (S), R4.1, R5.1, R6.1, R11.2, R12.1, R15.2, R16.1, R21.2, R22.2, R33.1, R41.1, S1.1 (COMMON_A), S1.4 (COMMON_B), SW1.2, U1.9 (RFGND), U1.13 (GND), U1.14 (GND), U1.16 (~SEN), U2.3 (GND), U2.11 (GND), U2.15 (GND), U2.17 (GND), U3.3 (GND), U3.11 (GND), U3.15 (GND), U3.17 (GND), U4.3 (GND_2), U4.9 (GND_3), U4.10 (GND_4), U4.13 (GND_5), U4.19 (GND), U4.21 (EP), U5.1 (GND), U5.7 (GND), U6.1 (GND), U6.11 (TP_GND), U7.2 (GND), U8.2 (GND), U8.13 (GND), U8.21 (GND), U9.2 (GND), U10.6 (GND), U10.7 (GND), U12.2 (GND), X1.2, X1.4, Y1.8 (GND), Y2.5 (VSS)
GPIO_INT: IC3.7 (~INT), J8.7, R36.2, U8.10 (GPIO0)
I2SCLK: J1.2, R3.1, U2.16 (BCLK), U3.16 (BCLK)
I2SDIN: J1.3, R9.2, U2.1 (DIN), U3.1 (DIN)
I2SLRC: J1.1, R10.1, U2.14 (LRCLK), U3.14 (LRCLK)
INT2: J7.7, U8.6 (GPIO4)
IO9: D3.1 (DIN), R40.2, U8.15 (GPIO9)
L: C13.2, R19.1, U1.24 (LOUT/[DFS])
LCD_BL: IC3.3 (P2), Q2.1 (G), R32.1, R33.2, T7.1
LCD_CS: J7.2, U6.6 (CS), U8.8 (GPIO2)
LCD_DC: J7.4, U6.5 (RS), U8.9 (GPIO1)
LEDK: Q2.3 (D), U6.2 (LEDK)
LORA: ANT4.1 (A), C27.1, D2.3 (K), U8.22 (LoRa_Ant)
LORA_BUSY: J7.3, U8.7 (GPIO3)
LORA_CS: U8.16 (GPIO8)
MISO: J8.5, U8.4 (GPIO6)
MOSI: J8.4, U6.8 (DAT), U8.3 (GPIO7)
unnamed: ANT1.1 (A), C6.1
unnamed: ANT2.1 (A), C19.1, L6.2
unnamed: ANT3.1 (A), C8.1, D1.3 (K), L5.2
unnamed: C9.1, C11.1, L2.2, L3.1
unnamed: C16.1, C17.1, L3.2, L6.1
unnamed: C18.1, L4.1
unnamed: D3.3 (DOUT), T4.1
unnamed: IC1.8 (AMI), L7.1
unnamed: C27.2, IC1.6 (FMI), L7.2
unnamed: IC1.2 (GPO3/DCLK), R18.2
unnamed: IC1.1 (LOUT/DFS), R19.2
unnamed: C32.2, IC1.13 (RCLK), R31.1
unnamed: IC1.16 (ROUT/DOUT), R28.1
unnamed: IC1.9 (~RST), R29.2
unnamed: IC3.6 (~RESET), R39.1
unnamed: J2.1, U2.10 (OUTN)
unnamed: J2.2, U2.9 (OUTP)
unnamed: J3.1, U3.10 (OUTN)
unnamed: J3.2, U3.9 (OUTP)
unnamed: J4.A5 (CC1), R15.1
unnamed: J4.B5 (CC2), R16.2
unnamed: C30.1, J5.1, R26.1
unnamed: C33.1, J5.3, R27.2
unnamed: L4.2, L5.1
unnamed: C18.2, Q1.3 (G), R11.1
unnamed: C7.1, U1.22 (DBYP)
unnamed: R10.2, U1.2 (DFS)
unnamed: R9.1, U1.1 (DOUT)
unnamed: C8.2, L1.2, U1.8 (FMI)
unnamed: R3.2, U1.3 (GPO3/[DCLK])
unnamed: R2.1, U1.19 (RCLK)
unnamed: R1.2, U1.15 (~RST)
unnamed: R4.2, U2.2 (GAIN)
unnamed: R7.1, U2.4 (SD)
unnamed: R5.2, U3.2 (GAIN)
unnamed: R6.2, R8.1, U3.4 (SD)
unnamed: C24.2, U4.17 (CPN)
unnamed: C24.1, U4.18 (CPP)
unnamed: C25.1, U4.15 (CPVSS_2), U4.16 (CPVSS)
unnamed: R27.1, U4.14 (HPLEFT)
unnamed: R26.2, U4.11 (HPRIGHT)
unnamed: C12.1, U4.1 (LEFTINM)
unnamed: C13.1, U4.2 (LEFTINP)
unnamed: C15.1, U4.5 (RIGHTINM)
unnamed: C14.1, U4.4 (RIGHTINP)
unnamed: R25.1, U4.8 (SCL)
unnamed: R24.1, U4.7 (SDA)
unnamed: R13.2, U4.6 (~SD)
unnamed: R30.2, U6.3 (LEDA)
unnamed: R34.1, U6.9 (RST)
unnamed: C35.2, R35.2, U8.11 (EN)
unnamed: R41.2, U12.6 (PROG)
unnamed: C5.1, L2.1, Y1.10 (CLK0)
unnamed: T1.1, Y1.9 (CLK1)
unnamed: C6.2, Y1.6 (CLK2)
unnamed: X1.1, Y1.2 (XA)
unnamed: X1.3, Y1.3 (XB)
unnamed: R22.1, T2.1, Y2.4 (EVI)
unnamed: R20.1, R21.1, Y2.1 (VBACKUP)
OSC: R2.2, R18.1, R31.2, Y2.7 (CLKOUT)
R: C14.2, R28.2, U1.23 (ROUT/[DOUT])
RV3028_Int: R23.2, R36.1, T3.1, Y2.3 (~INT)
SCL: IC1.11 (SCLK), IC2.1 (SCL), IC3.8 (SCL), IC4.4 (SCL), J7.6, R14.2, R25.2, U1.17 (SCLK), U5.4 (SCK), U6.15 (TP_SCL), U8.20 (GPIO21_TXD), U10.13 (SCL), Y1.4 (SCL), Y2.8 (SCL)
SDA: IC1.12 (SDIO), IC2.4 (SDA), IC3.9 (SDA), IC4.1 (SDA), J7.5, R17.2, R24.2, U1.18 (SDIO), U5.3 (SDI), U6.14 (TP_SDA), U8.19 (GPIO20_RXD), U10.14 (SDA), Y1.5 (SDA), Y2.2 (SDA)
SWITCH1: IC3.1 (P0), S1.3, T5.1
SWITCH2: IC3.2 (P1), S1.2, T6.1
TP2_INT: IC3.4 (P3), T8.1, U6.13 (TP_INT)

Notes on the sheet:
I2C Address - LSM6 6B - SI5351 0x60 !!! - BQ25186 0X6A - TPA6130 0x60!!!! - SI4735 0x11 oder 0x63 - SI4732 0x11 - TCA9537 0x49
RT9013 3.3V LDO Power Supply Dedicated Power Supply for Radio to limit Noise
SI4732 with Analog Audio
Solder R27 if NO Backup Batt
R14 not connected
MAX98357 Audio AMP
3V3
Funktionen - FM Radio - Frequuenzgenerator SI5331 - WebRadio - RF Weather Station Reader - LoRa Transmitter - LED Nachtlicht - BikeComputer
Light Sensor
WS2812 DEBUG LED
Seeed-Studio-Xiao-Connector
IO-Extender TCA9357
RV3032-C7 Real time clock
SI5331 VCO: 10KHz - 200MHz
https://reflector.sota.org.uk/t/ sotabeams-2m-bandpass-filter/35032
BME690 Air-Q
HT-CT62 ESP32-C3+SX1262 LoRa/Meshtastic/TTN/Helium
25MHz
L2 vs L2 in 90° Angle
SI4735 with I2S Out
GND
R18 Pad Umbaubar auf Quarz mit 22pF
ST77916 1.8" Display
GPS Module

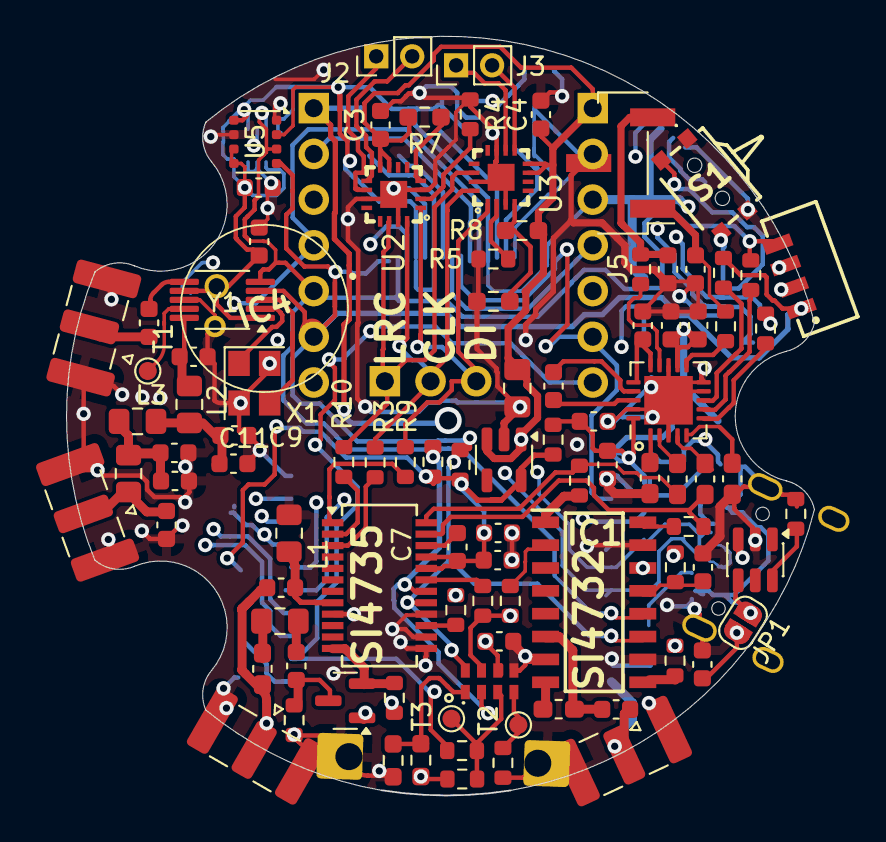
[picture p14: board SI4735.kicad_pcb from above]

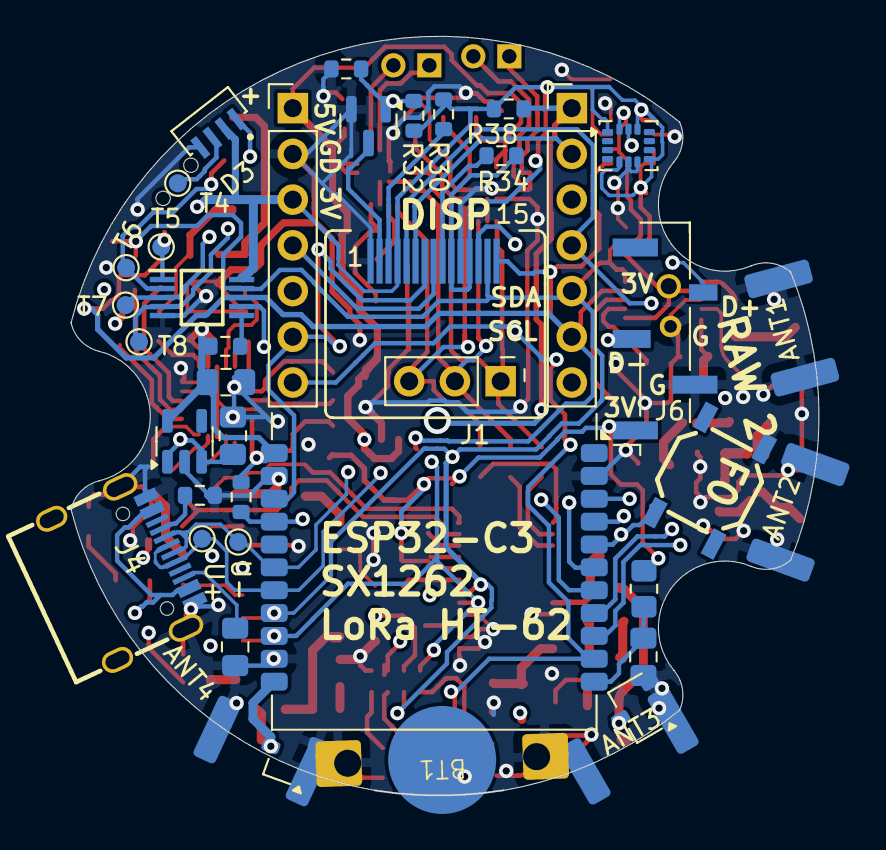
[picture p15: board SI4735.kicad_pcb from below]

Board: 4 copper layers, 41.6 x 42.2 mm, 133 parts (36 on the bottom side), 93 nets.

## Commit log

2025-12-16 Initial Upload
    [SI4735.kicad_pcb, SI4735.kicad_sch, bom.csv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]
2025-12-16 Update README.md
    Added Schematic IMG
2025-12-19 Add files via upload
    - Rotation of SI4732 Radio
    - Added Battery Charging IC TP4057
    - Added Light Sensor VEML7700
    [SI4735.kicad_pcb, SI4735.kicad_sch, bom.csv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]
2025-12-21 Add files via upload
    - Added MLX90640 Thermal Camera
    - Refinement of inner Layers to enhance EMC
    [SI4735.kicad_pcb, SI4735.kicad_sch, bom.csv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]
2025-12-22 Updated to last Design with rotated SI4732
    - Added Battery charger
    - Added MLX90640 Thermal CAM
    - Added rotation of SI4732 Chip
    - Renamed Chips
2025-12-22 Add files via upload
    Added new Schematic File
